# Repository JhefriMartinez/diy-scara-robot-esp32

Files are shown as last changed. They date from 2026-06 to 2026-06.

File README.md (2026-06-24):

# Manipulador Robótico SCARA de 3 GDL (RRP)

Este repositorio contiene los archivos de diseño mecánico, firmware embebido y software de control para el desarrollo de un robot manipulador tipo SCARA de 3 grados de libertad con configuración Revoluta-Revoluta-Prismática (RRP), fabricado mediante impresión 3D (PLA).

## 👥 Integrantes
* Edson Alvarez Chavez
* Jhefri Franco Martinez Cardenas
* Dave Sebastian Peñares Cuya
* Carlos Unocc Manrique

## 🛠️ Arquitectura del Sistema
* **Hardware Estructural:** Eslabones optimizados impresos en PLA (FDM).
* **Controlador Central:** Microcontrolador ESP32-DevKit V1.
* **Módulo de Potencia:** Driver PWM PCA9685 de 16 canales e interfaz I2C.
* **Actuadores:** Servomotores MG995 (alto torque) y microservo MG90S para el efector final (garra).
* **Fuente de Alimentación:** Fuente conmutada AWERS de 5VDC a 10A.

## 💻 Estructura del Repositorio
* `1_Firmware_ESP32/`: Código fuente en C++ (Arduino IDE) encargado de la recepción de tramas por UART, parsing de datos y ejecución local de la cinemática inversa embebida.
* `2_Interfaz_Python/`: Script en Python utilizando `customtkinter` para la teleoperación de consignas cartesianas y simulación predictiva 3D con `matplotlib`.
* `3_Diseño_CAD_STL/`: Modelos geométricos en formato STL listos para laminación e impresión 3D.

## 🚀 Instrucciones de Uso
1. Cargar el firmware del ESP32 ubicado en la carpeta correspondiente.
2. Energizar la etapa de potencia física con la fuente conmutada.
3. Ejecutar el script de Python `interfaz_scara.py` en la computadora maestra, seleccionar el puerto COM asignado y presionar "Conectar".
4. Introducir las coordenadas deseadas dentro del espacio de trabajo seguro (Radio: 11.75 - 16.60 cm, Z: 0.00 - 3.11 cm).

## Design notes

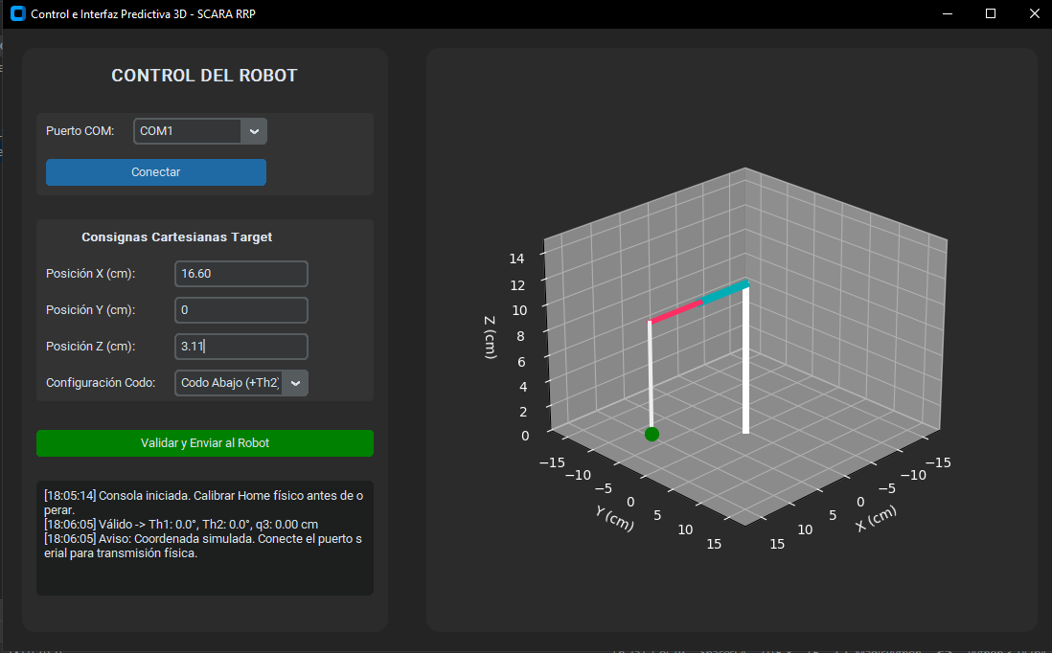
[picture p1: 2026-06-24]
2_Interfaz_Python/anteprima_interfaz.PNG

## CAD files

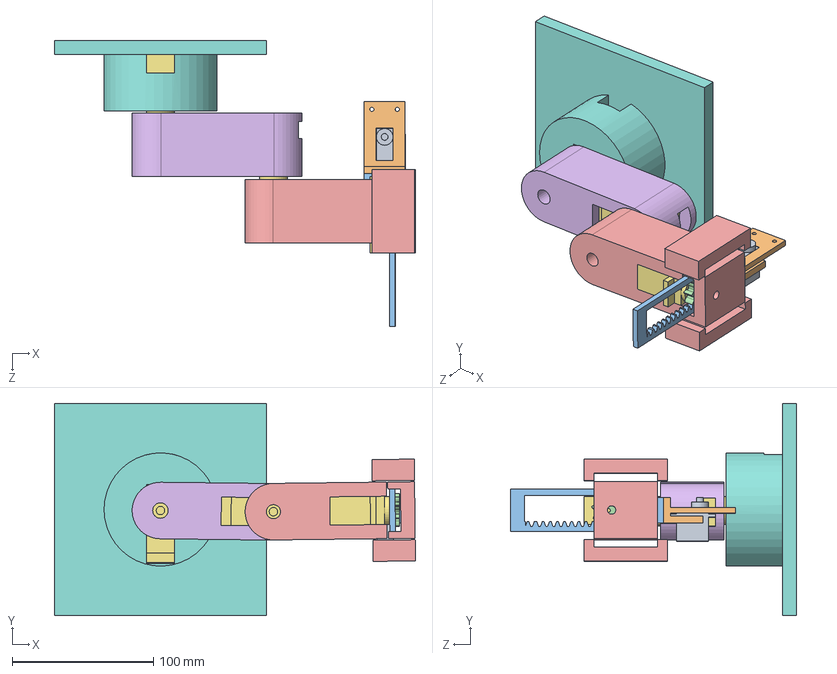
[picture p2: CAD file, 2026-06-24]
3_Diseño_CAD_STL/ensamblaje/Ensamblaje1.SLDASM
255.2 x 150.0 x 202.2 mm
2 PROTOTIPO BASE SCARA
servo mg995 x 3
2 PROTOTIPO ESLABON 1 SCARA
2 PROTOTIPO ESLABON 2 SCARA
ENGRANAJE 1 SCARA
1 prototipo cremallera scara
base del griper
servo motor mg95

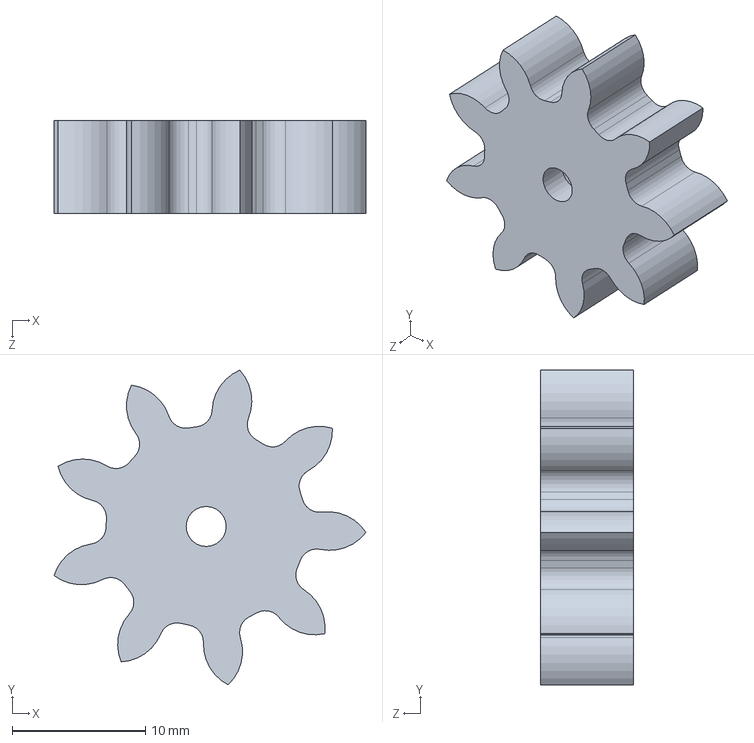
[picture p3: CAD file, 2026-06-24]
3_Diseño_CAD_STL/ENGRANAJE 1 SCARA.SLDPRT
23.4 x 23.6 x 7.00 mm

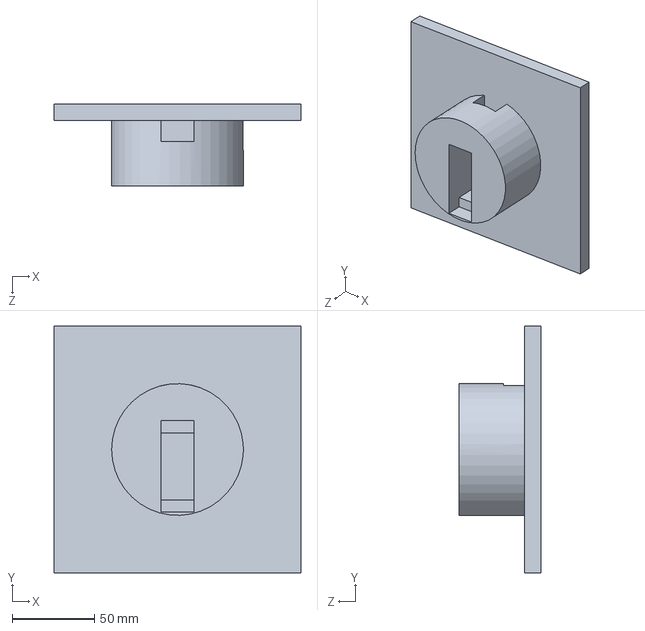
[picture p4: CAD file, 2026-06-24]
3_Diseño_CAD_STL/2 PROTOTIPO BASE SCARA.SLDPRT
150.0 x 150.0 x 50.0 mm

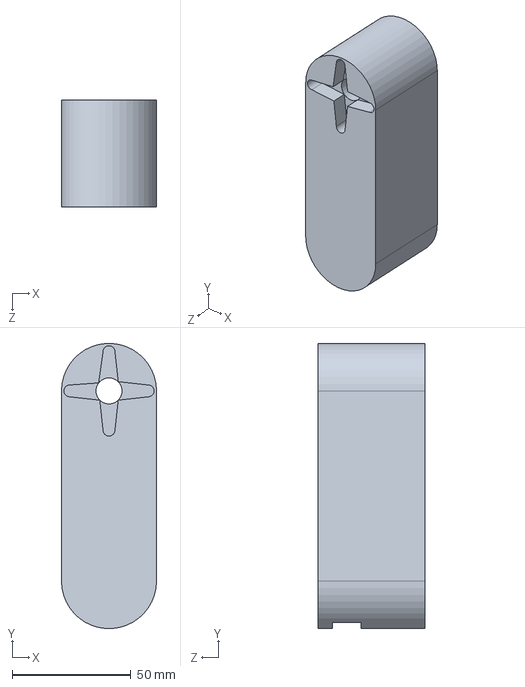
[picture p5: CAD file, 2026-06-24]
3_Diseño_CAD_STL/2 PROTOTIPO ESLABON 1 SCARA.SLDPRT
40.0 x 119.9 x 45.0 mm

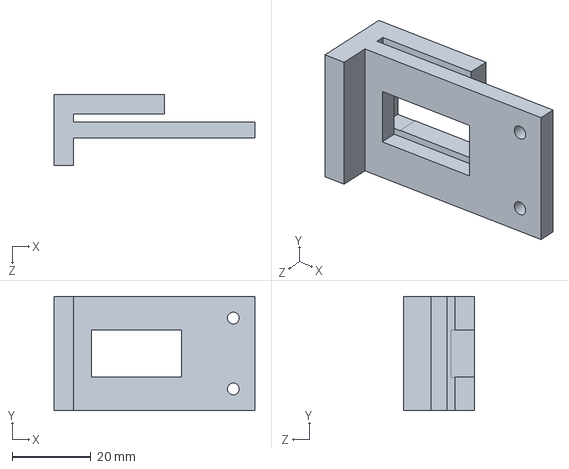
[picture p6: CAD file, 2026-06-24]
3_Diseño_CAD_STL/base del griper.SLDPRT
51.0 x 29.0 x 18.0 mm

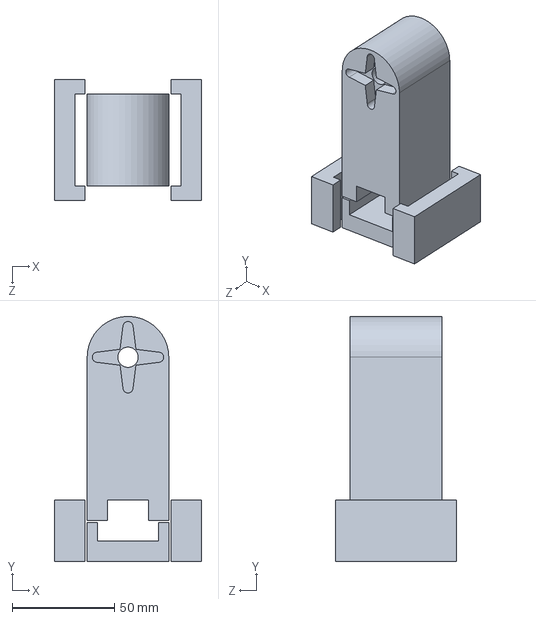
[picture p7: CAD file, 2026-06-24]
3_Diseño_CAD_STL/2 PROTOTIPO ESLABON 2 SCARA.SLDPRT
72.0 x 119.9 x 59.0 mm

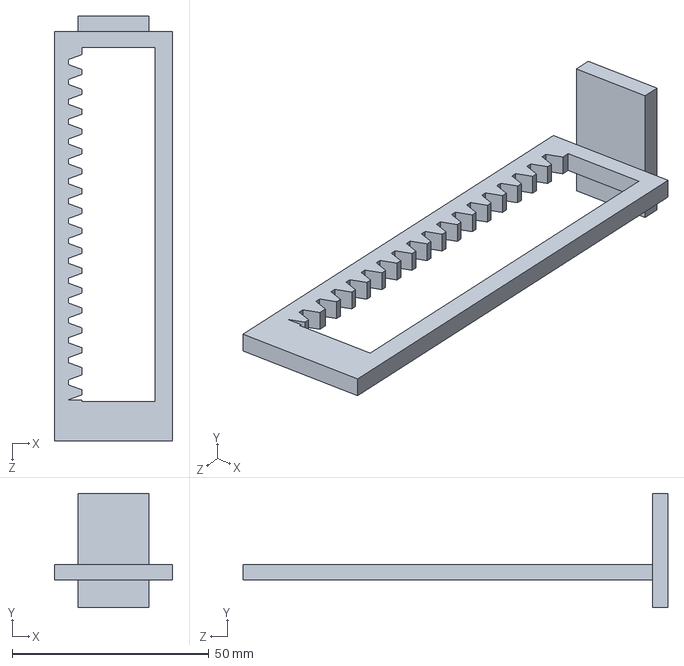
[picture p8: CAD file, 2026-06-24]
3_Diseño_CAD_STL/1 prototipo cremallera scara.SLDPRT
30.0 x 29.0 x 108.0 mm

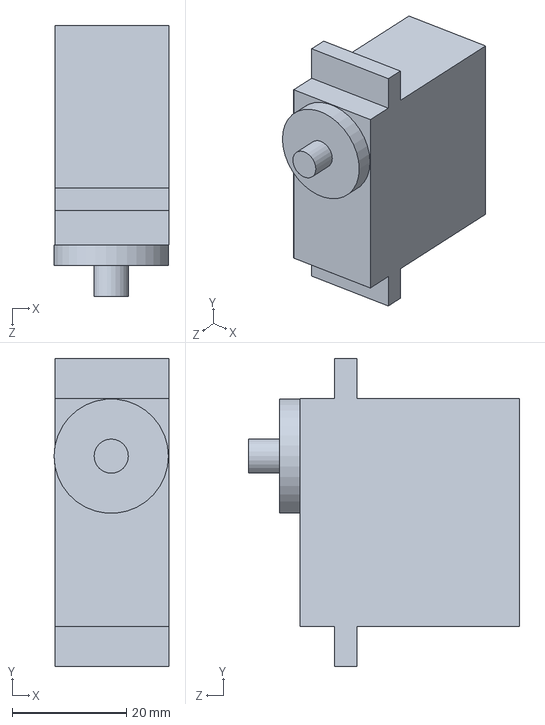
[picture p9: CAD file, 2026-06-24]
3_Diseño_CAD_STL/servo mg995.SLDPRT
20.1 x 54.0 x 47.6 mm

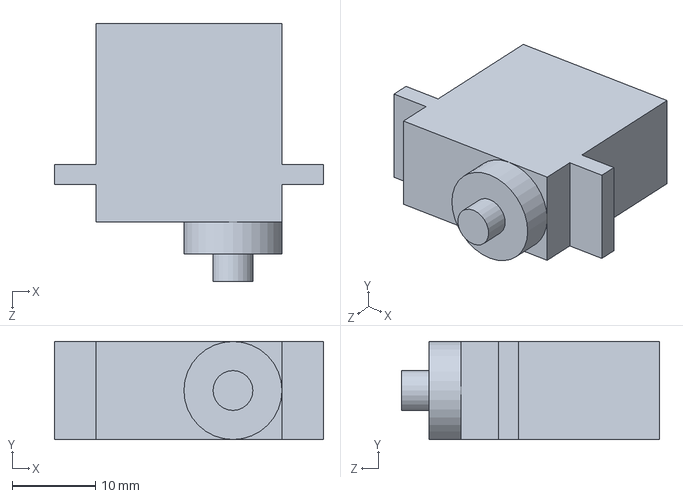
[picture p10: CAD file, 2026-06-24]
3_Diseño_CAD_STL/servo motor mg95.SLDPRT
32.4 x 11.8 x 31.1 mm

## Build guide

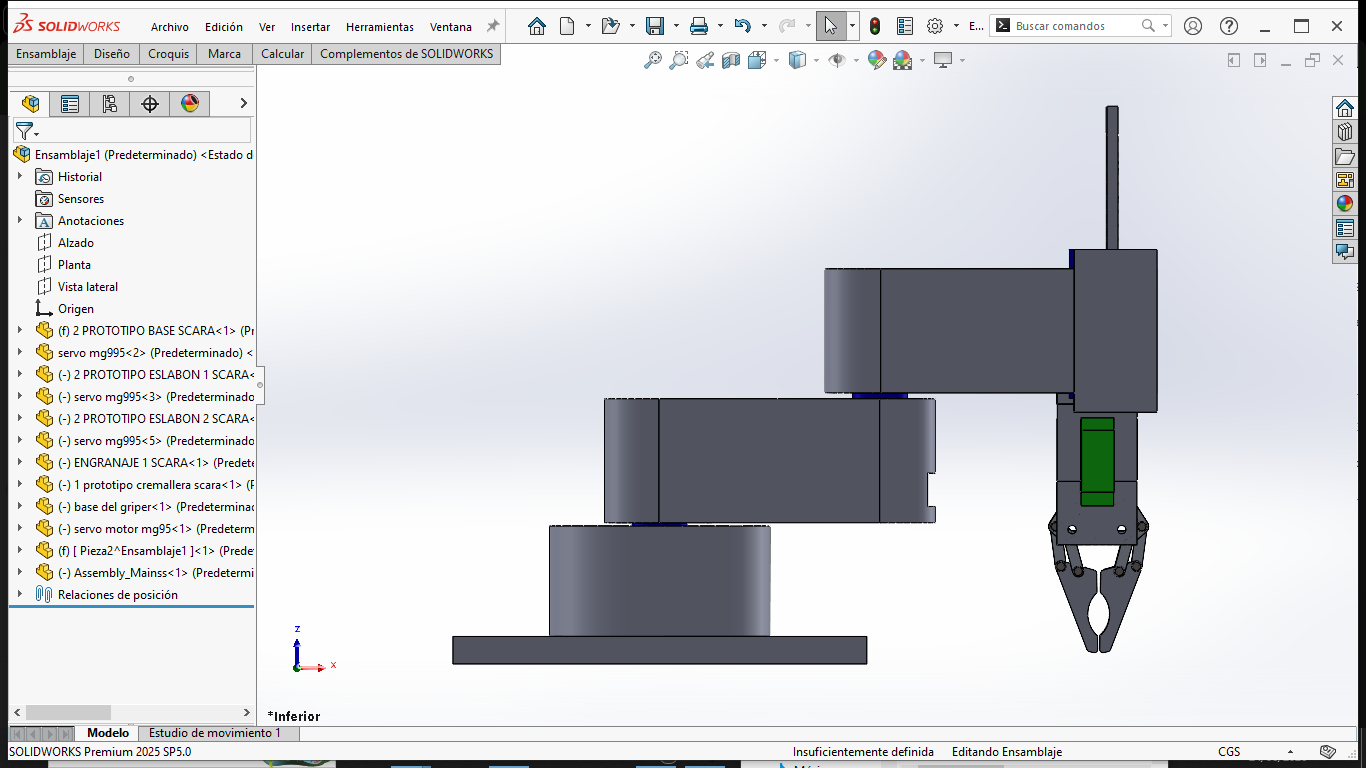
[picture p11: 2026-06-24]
3_Diseño_CAD_STL/anteprima_ensamblaje.PNG

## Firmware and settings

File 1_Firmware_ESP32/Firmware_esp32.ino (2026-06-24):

#include <Wire.h>
#include <Adafruit_PWMServoDriver.h>

// Instancia del controlador driver PCA9685 por bus I2C estándar
Adafruit_PWMServoDriver pwm = Adafruit_PWMServoDriver();

// Constantes físicas del robot SCARA (idénticas a la matriz del informe)
const float L2 = 7.99;
const float L3 = 8.61;

// Calibración sintonizada de microsegundos nominales para los actuadores
// NOTA: Ajusta el offset de calibración física sumando/restando grados AQUÍ
const float OFFSET_BASE_MOTOR = 0.0; // Desfase fino del piñón en grados
const float OFFSET_CODO_MOTOR = 0.0; // Ajuste fino del codo en grados

void setup() {
  // Inicialización de la comunicación serial maestro-esclavo a 115200 bps
  Serial.begin(115200);
  
  // Inicialización del controlador driver PCA9685 en dirección por defecto 0x40
  pwm.begin();
  pwm.setOscillatorFrequency(27000000);
  pwm.setPWMFreq(50); // Frecuencia de actualización nominal a 50 Hz (período de 20 ms)

  // Mapeo inicial preventivo: Mover el robot a postura de calibración Home seguro
  moverRobotA_Coordenadas(16.60, 0.00, 3.11);
  delay(500);
}

void loop() {
  // Escucha activa y parsing serial asíncrono sin bloqueo de ciclo
  if (Serial.available() > 0) {
    String trama = Serial.readStringUntil('\n');
    trama.trim();
    
    if (trama.length() > 0) {
      int primerComa = trama.indexOf(',');
      int segundoComa = trama.indexOf(',', primerComa + 1);
      
      if (primerComa != -1 && segundoComa != -1) {
        // Extracción de componentes numéricos de la cadena serial
        float px = trama.substring(0, primerComa).toFloat();
        float py = trama.substring(primerComa + 1, segundoComa).toFloat();
        float pz = trama.substring(segundoComa + 1).toFloat();
        
        // Ejecución en vivo de la capa de cálculo cinemático inverso
        moverRobotA_Coordenadas(px, py, pz);
      }
    }
  }
}

void moverRobotA_Coordenadas(float px, float py, float pz) {
  // 1. RESOLUCIÓN DE LA ARTICULACIÓN PRISMÁTICA q3 (Componente vertical matricial)
  if (pz < 0.0) pz = 0.0;
  if (pz > 3.11) pz = 3.11;
  float q3 = 3.11 - pz;

  // 2. RESOLUCIÓN ALGEBRAICA EN PLANO HORIZONTAL (Deducción exacta de las láminas)
  float radio_sq = (px * px) + (py * py);
  
  float num_th2 = radio_sq - (L2 * L2) - (L3 * L3);
  float den_th2 = 2.0 * L2 * L3;
  float cos_th2 = num_th2 / den_th2;
  
  // Protección estricta del firmware contra desborde de memoria (NaN / Imaginarios)
  if (cos_th2 > 1.0) cos_th2 = 1.0;
  if (cos_th2 < -1.0) cos_th2 = -1.0;

  // Configuración por defecto: Codo Abajo (Signo algebraico positivo)
  float sin_th2 = sqrt(1.0 - (cos_th2 * cos_th2));
  float theta2 = atan2(sin_th2, cos_th2);

  // Solución analítica para Theta 1
  float num_th1 = py * (L2 + L3 * cos_th2) - px * (L3 * sin_th2);
  float den_th1 = px * (L2 + L3 * cos_th2) + py * (L3 * sin_th2);
  float theta1 = atan2(num_th1, den_th1);

  // Convertir radianes del cálculo matricial a grados decimales prácticos
  float th1_deg = theta1 * 180.0 / M_PI;
  float th2_deg = theta2 * 180.0 / M_PI;

  // 3. CAPA DE POTENCIA Y EJECUCIÓN FÍSICA (SATURACIÓN Y MAPEO PWM)
  
  // --- ARTICULACIÓN 1: NUEVO MOTOR DE 270 GRADOS ---
  // Rango cinemático [-135, 135] se desvía mediante un offset de +135 a rango positivo [0, 270]
  float th1_positivo = th1_deg + 135.0 + OFFSET_BASE_MOTOR;
  if (th1_positivo < 0.0) th1_positivo = 0.0;
  if (th1_positivo > 270.0) th1_positivo = 270.0;
  
  // Mapeo lineal exacto sobre el rango total de 270 grados
  int pulsoMicros0 = map(th1_positivo, 0, 270, 500, 2500);
  int pasosPCA0 = (pulsoMicros0 * 4096) / 20000;
  pwm.setPWM(0, 0, pasosPCA0); // Canal 0: Base Física

  // --- ARTICULACIÓN 2: MOTOR DEL CODO DE 180 GRADOS ---
  // Rango cinemático [-90, 90] se desvía mediante un offset de +90 a rango positivo [0, 180]
  float th2_positivo = th2_deg + 90.0 + OFFSET_CODO_MOTOR;
  if (th2_positivo < 0.0) th2_positivo = 0.0;
  if (th2_positivo > 180.0) th2_positivo = 180.0;
  
  int pulsoMicros1 = map(th2_positivo, 0, 180, 500, 2500);
  int pasosPCA1 = (pulsoMicros1 * 4096) / 20000;
  pwm.setPWM(1, 0, pasosPCA1); // Canal 1: Codo Físico

  // --- ARTICULACIÓN 3: EJE PRISMÁTICO (PIÑÓN-CREMALLERA) ---
  // Carrera lineal mapeada directamente de 0 a 3.11 cm hacia los límites del motor
  if (q3 < 0.0) q3 = 0.0;
  if (q3 > 3.11) q3 = 3.11;
  
  int pulsoMicros2 = map(q3 * 100.0, 0, 311, 500, 2500); // Conversión a enteros en mm
  int pasosPCA2 = (pulsoMicros2 * 4096) / 20000;
  pwm.setPWM(2, 0, pasosPCA2); // Canal 2: Elevación Lineal
}

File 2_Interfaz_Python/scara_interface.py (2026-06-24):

import customtkinter as ctk
import numpy as np
import serial
import serial.tools.list_ports
import threading
import time
import matplotlib.pyplot as plt
from matplotlib.backends.backend_tkagg import FigureCanvasTkAgg
from mpl_toolkits.mplot3d import Axes3D

class ScaraGUI(ctk.CTk):
    def __init__(self):
        super().__init__()
        
        # Parámetros geométricos confirmados (cm)
        self.L1 = 11.61
        self.L2 = 7.99
        self.L3 = 8.61
        self.arduino = None
        
        # Configuración de la ventana maestra
        self.title("Control e Interfaz Predictiva 3D - SCARA RRP")
        self.geometry("1100x650")
        ctk.set_appearance_mode("Dark")
        ctk.set_default_color_theme("blue")
        
        self.protocol("WM_DELETE_WINDOW", self.on_closing)
        self.crear_interfaz()
        
    def crear_interfaz(self):
        # Grid principal de 2 columnas
        self.grid_columnconfigure(0, weight=1)
        self.grid_columnconfigure(1, weight=2)
        self.grid_rowconfigure(0, weight=1)
        
        # --------- PANEL DE CONTROL DE HARDWARE (IZQUIERDA) ---------
        self.frame_izq = ctk.CTkFrame(self, width=350, corner_radius=15)
        self.frame_izq.grid(row=0, column=0, padx=20, pady=20, sticky="nsew")
        
        self.lbl_titulo = ctk.CTkLabel(self.frame_izq, text="CONTROL DEL ROBOT", font=ctk.CTkFont(size=18, weight="bold"))
        self.lbl_titulo.pack(pady=15)
        
        # Conexión Serial
        self.frame_serial = ctk.CTkFrame(self.frame_izq)
        self.frame_serial.pack(fill="x", padx=15, pady=10)
        
        self.lbl_port = ctk.CTkLabel(self.frame_serial, text="Puerto COM:")
        self.lbl_port.grid(row=0, column=0, padx=10, pady=5)
        
        puertos = [p.device for p in serial.tools.list_ports.comports()]
        if not puertos: puertos = ["COM1", "COM2", "COM3", "COM4"]
        self.combo_puertos = ctk.CTkComboBox(self.frame_serial, values=puertos)
        self.combo_puertos.grid(row=0, column=1, padx=10, pady=5)
        
        self.btn_conectar = ctk.CTkButton(self.frame_serial, text="Conectar", command=self.toggle_conexion)
        self.btn_conectar.grid(row=1, column=0, columnspan=2, pady=10, padx=10, sticky="ew")
        
        # Entradas de Coordenadas Cartesianas (cm)
        self.frame_coord = ctk.CTkFrame(self.frame_izq)
        self.frame_coord.pack(fill="x", padx=15, pady=15)
        
        self.lbl_coord_title = ctk.CTkLabel(self.frame_coord, text="Consignas Cartesianas Target", font=ctk.CTkFont(weight="bold"))
        self.lbl_coord_title.grid(row=0, column=0, columnspan=2, pady=5)
        
        # Entrada X
        ctk.CTkLabel(self.frame_coord, text="Posición X (cm):").grid(row=1, column=0, padx=10, pady=5, sticky="w")
        self.ent_x = ctk.CTkEntry(self.frame_coord, placeholder_text="13.0")
        self.ent_x.insert(0, "13.0")
        self.ent_x.grid(row=1, column=1, padx=10, pady=5)
        
        # Entrada Y
        ctk.CTkLabel(self.frame_coord, text="Posición Y (cm):").grid(row=2, column=0, padx=10, pady=5, sticky="w")
        self.ent_y = ctk.CTkEntry(self.frame_coord, placeholder_text="5.0")
        self.ent_y.insert(0, "5.0")
        self.ent_y.grid(row=2, column=1, padx=10, pady=5)
        
        # Entrada Z
        ctk.CTkLabel(self.frame_coord, text="Posición Z (cm):").grid(row=3, column=0, padx=10, pady=5, sticky="w")
        self.ent_z = ctk.CTkEntry(self.frame_coord, placeholder_text="2.0")
        self.ent_z.insert(0, "2.0")
        self.ent_z.grid(row=3, column=1, padx=10, pady=5)
        
        # Configuración de Codo (Matriz + / -)
        ctk.CTkLabel(self.frame_coord, text="Configuración Codo:").grid(row=4, column=0, padx=10, pady=5, sticky="w")
        self.opc_codo = ctk.CTkComboBox(self.frame_coord, values=["Codo Abajo (+Th2)", "Codo Arriba (-Th2)"])
        self.opc_codo.set("Codo Abajo (+Th2)")
        self.opc_codo.grid(row=4, column=1, padx=10, pady=5)
        
        # Botón Enviar Comando
        self.btn_enviar = ctk.CTkButton(self.frame_izq, text="Validar y Enviar al Robot", fg_color="green", hover_color="darkgreen", command=self.procesar_y_enviar)
        self.btn_enviar.pack(fill="x", padx=15, pady=15)
        
        # Consola de Estado Interna
        self.txt_log = ctk.CTkTextbox(self.frame_izq, height=120)
        self.txt_log.pack(fill="x", padx=15, pady=10)
        self.log("Consola iniciada. Calibrar Home físico antes de operar.")
        
        # --------- PANEL DE VISUALIZACIÓN MATPLOTLIB (DERECHA) ---------
        self.frame_der = ctk.CTkFrame(self, corner_radius=15)
        self.frame_der.grid(row=0, column=1, padx=20, pady=20, sticky="nsew")
        
        self.fig = plt.figure(figsize=(5, 5), facecolor='#2b2b2b')
        self.ax = self.fig.add_subnet(111, projection='3d') if hasattr(self.fig, 'add_subnet') else self.fig.add_subplot(111, projection='3d')
        self.ax.set_facecolor('#2b2b2b')
        
        self.canvas = FigureCanvasTkAgg(self.fig, master=self.frame_der)
        self.canvas.get_tk_widget().pack(fill="both", expand=True, padx=10, pady=10)
        
        # Render inicial en postura de Home Seguro
        self.graficar_brazo(16.60, 0.0, 3.11, 0.0, 0.0, 0.0)

    def log(self, mensaje):
        self.txt_log.insert("end", f"[{time.strftime('%H:%M:%S')}] {mensaje}\n")
        self.txt_log.see("end")

    def toggle_conexion(self):
        if self.arduino is None:
            try:
                puerto = self.combo_puertos.get()
                self.arduino = serial.Serial(puerto, 115200, timeout=1)
                time.sleep(2)  # Reset de cortesía del ESP32
                self.log(f"Conectado con éxito a {puerto} a 115200 bps.")
                self.btn_conectar.configure(text="Desconectar", fg_color="red", hover_color="darkred")
            except Exception as e:
                self.log(f"Error de conexión: {str(e)}")
        else:
            self.arduino.close()
            self.arduino = None
            self.log("Puerto Serial cerrado limpiamente.")
            self.btn_conectar.configure(text="Conectar", fg_color=["#3a7ebf", "#1f538d"], hover_color=["#326699", "#14375e"])
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
